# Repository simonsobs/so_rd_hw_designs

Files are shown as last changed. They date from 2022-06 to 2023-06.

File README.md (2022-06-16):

# so_rd_hw_designs
For storing design and fabrication files for circuit boards and other hardware within the readout and detector working group in a version controlled way.

## 300K LNA hardware
Ultimately, the printed circuit board (PCB) and power supply box designs should live here.

### 300K LNA PCB
The directories under`300k_amp_ps_box/pcb` contain all the files necessary for editing, fabricating, and viewing the 300K LNA circuit boards.
`300k_amp_ps_box/pcb/Bottom_board` contains a picture of the electronics schematic for the bottom board, a .step file which is a 3D model of the bottom board, and the gerber files necessary to manufacture the bottom circuit board (under `Project_Outputs_for_Bottom_Board`).
This same exact structure exists under`300k_amp_ps_box/pcb/Top_board` but instead describes the Top board of the 300K LNA PCB. In addition, [here are the assembly documents for both Top and Bottom boards](https://docs.google.com/presentation/d/1A_KDBGtZD-UfWHo1MMT_YvrvhtoMr0XffyKuqTHIMP8/edit?usp=sharing) 

#### Editing and Viewing the 300K LNA PCB with Altium
The user should copy the contents of the "altium_files" directory and place them into the directory in which their copy of Altium lives. Specifically, the user should:
  1. Copy all _directories_ under `300k_amp_ps_box/pcb/altium_files/Projects` into their Altium/Projects directory. 
  2. Place all files in `300k_amp_ps_box/pcb/altium_files/Library/ExportIntLib` into their Altium/Library/ExportIntLib directory OR just copy and place the ExportIntLib directory under User/Path/to/Altium/Library. 
  3. Open Altium and navigate to Open Project
  4. Open `300k_amp_filtered_PS_supply` to see the entire PCB project. The Top and Bottom board projects exist because the 300k_amp_filtered_PS_supply _composed of_ the two smaller projects: `Top_board` and `Bottom_board`.
  5. User should now be able to view and edit the boards. User can reference [The Altium tutorial documents](https://www.altium.com/documentation/altium-designer/tutorial-complete-design-walkthrough) for a quick guide to make edits within Altium.

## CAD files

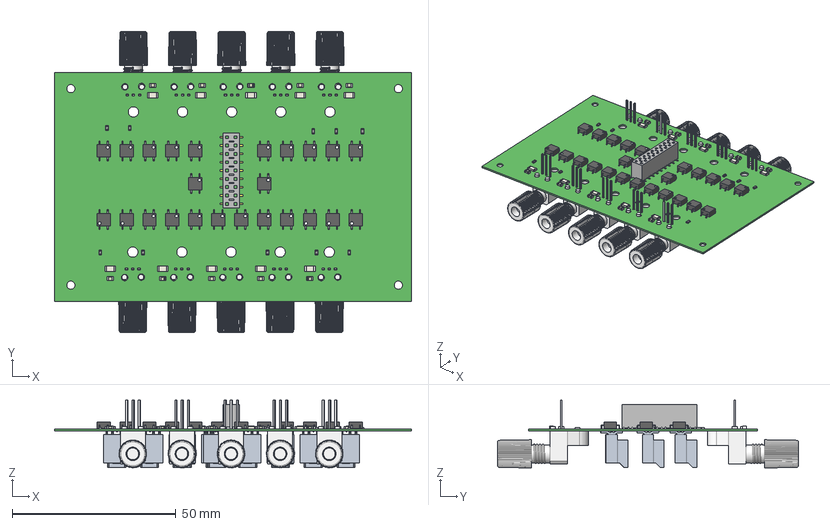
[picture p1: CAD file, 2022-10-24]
300k_amp_ps_box/pcb/Top_board/top_board_rev10_3.step
109.0 x 91.9 x 20.8 mm
C-137-019
SSM-109-STL-DV_body
Vishay_logo_-_Copy x 10
Vishay_logo x 10
Cap_KEMET_C0805C472J3HAC_eec x 30
Extruded x 54
3dmodel x 144
Detector x 10

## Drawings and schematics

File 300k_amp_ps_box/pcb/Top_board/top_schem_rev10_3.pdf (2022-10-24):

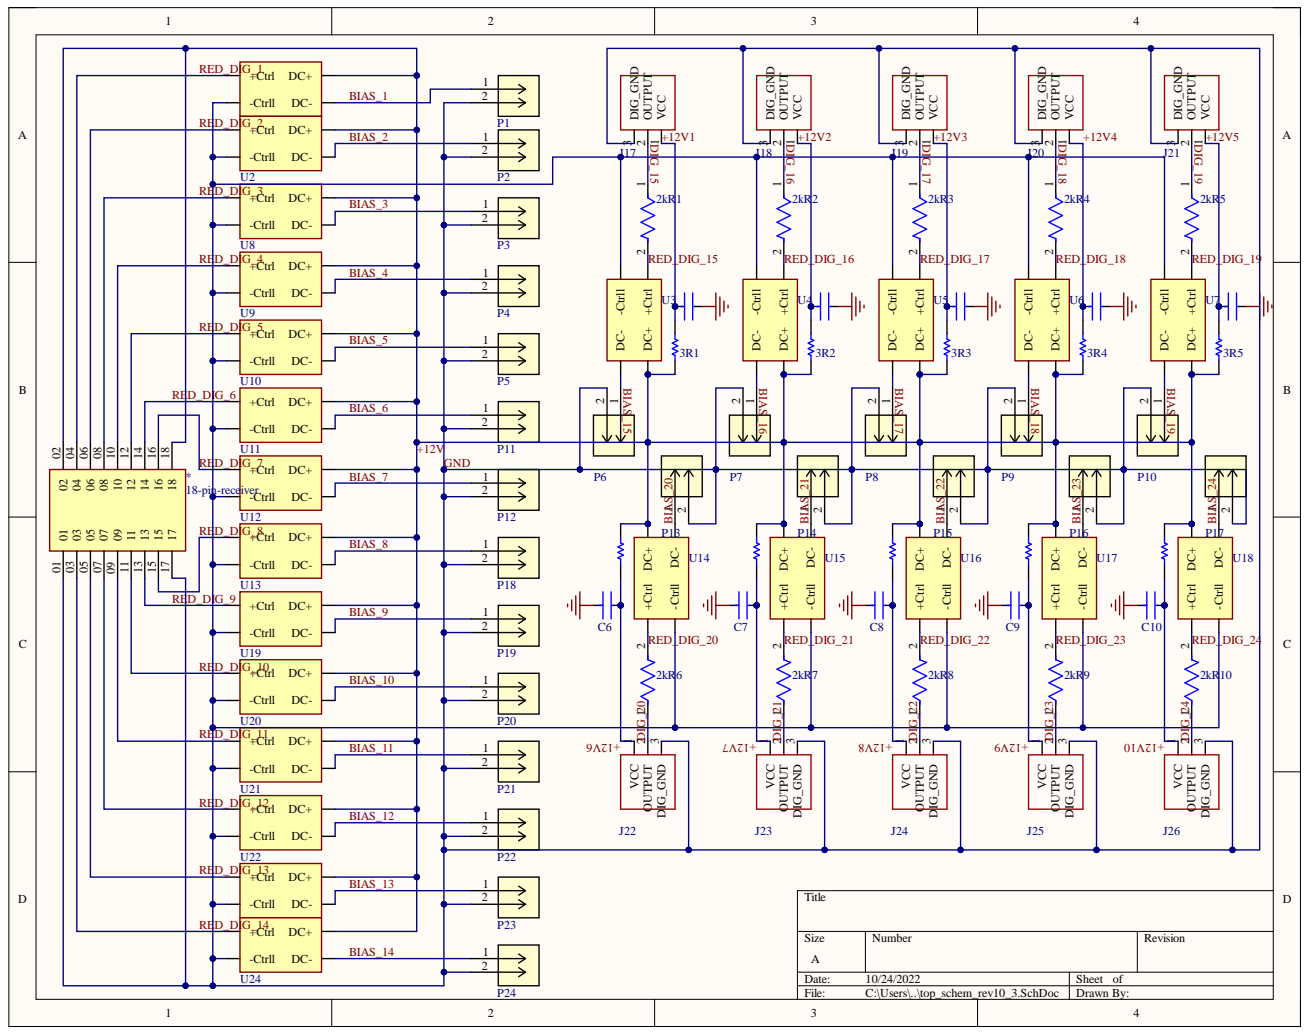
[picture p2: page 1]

BIAS_13

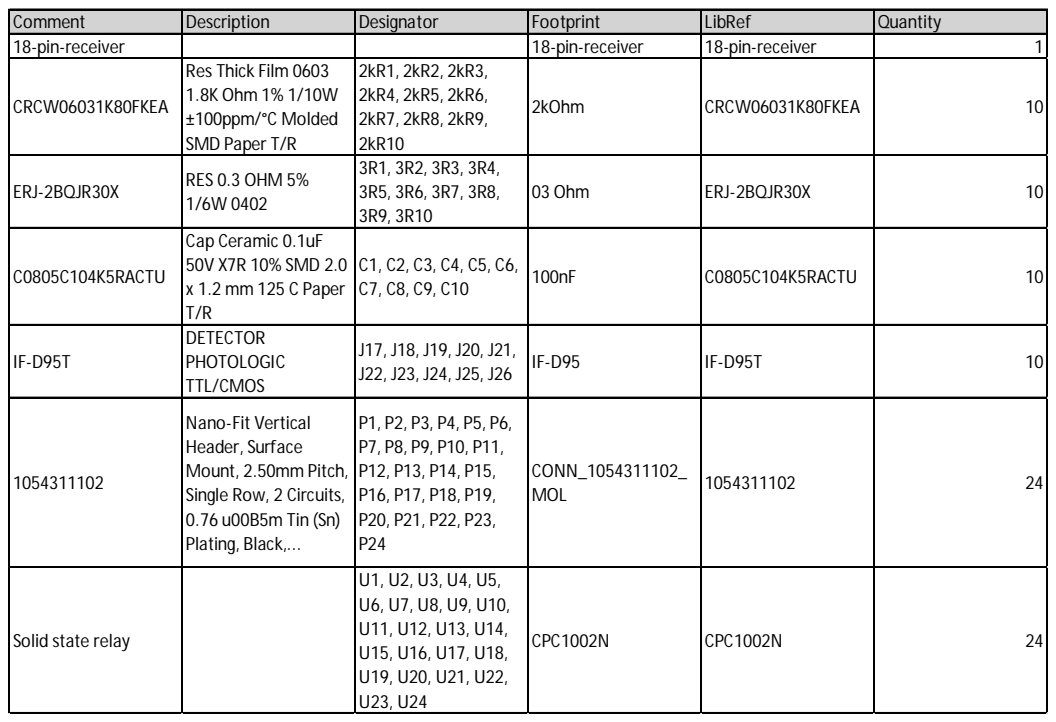
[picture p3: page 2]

Comment | Description | Designator | Footprint | LibRef | Quantity
18-pin-receiver | | | 18-pin-receiver | 18-pin-receiver | 1
CRCW06031K80FKEA | Res Thick Film 0603 1.8K Ohm 1% 1/10W ±100ppm/°C Molded SMD Paper T/R | 2kR1, 2kR2, 2kR3, 2kR4, 2kR5, 2kR6, 2kR7, 2kR8, 2kR9, 2kR10 | 2kOhm | CRCW06031K80FKEA | 10

ERJ-2BQJR30X | RES 0.3 OHM 5% 1/6W 0402 | 3R1, 3R2, 3R3, 3R4, 3R5, 3R6, 3R7, 3R8, 3R9, 3R10 | 03 Ohm | ERJ-2BQJR30X | 10

C0805C104K5RACTU | Cap Ceramic 0.1uF 50V X7R 10% SMD 2.0 x 1.2 mm 125 C Paper T/R | C1, C2, C3, C4, C5, C6, C7, C8, C9, C10 | 100nF | C0805C104K5RACTU | 10

IF-D95T | DETECTOR PHOTOLOGIC TTL/CMOS | J17, J18, J19, J20, J21, J22, J23, J24, J25, J26 | IF-D95 | IF-D95T | 10

1054311102 | Nano-Fit Vertical Header, Surface Mount, 2.50mm Pitch, Single Row, 2 Circuits, 0.76 u00B5m Tin (Sn) Plating, Black,... | P1, P2, P3, P4, P5, P6, P7, P8, P9, P10, P11, P12, P13, P14, P15, P16, P17, P18, P19, P20, P21, P22, P23, P24 | CONN_1054311102_ MOL | 1054311102 | 24

Solid state relay | | U1, U2, U3, U4, U5, U6, U7, U8, U9, U10, U11, U12, U13, U14, U15, U16, U17, U18, U19, U20, U21, U22, U23, U24 | CPC1002N | CPC1002N | 24

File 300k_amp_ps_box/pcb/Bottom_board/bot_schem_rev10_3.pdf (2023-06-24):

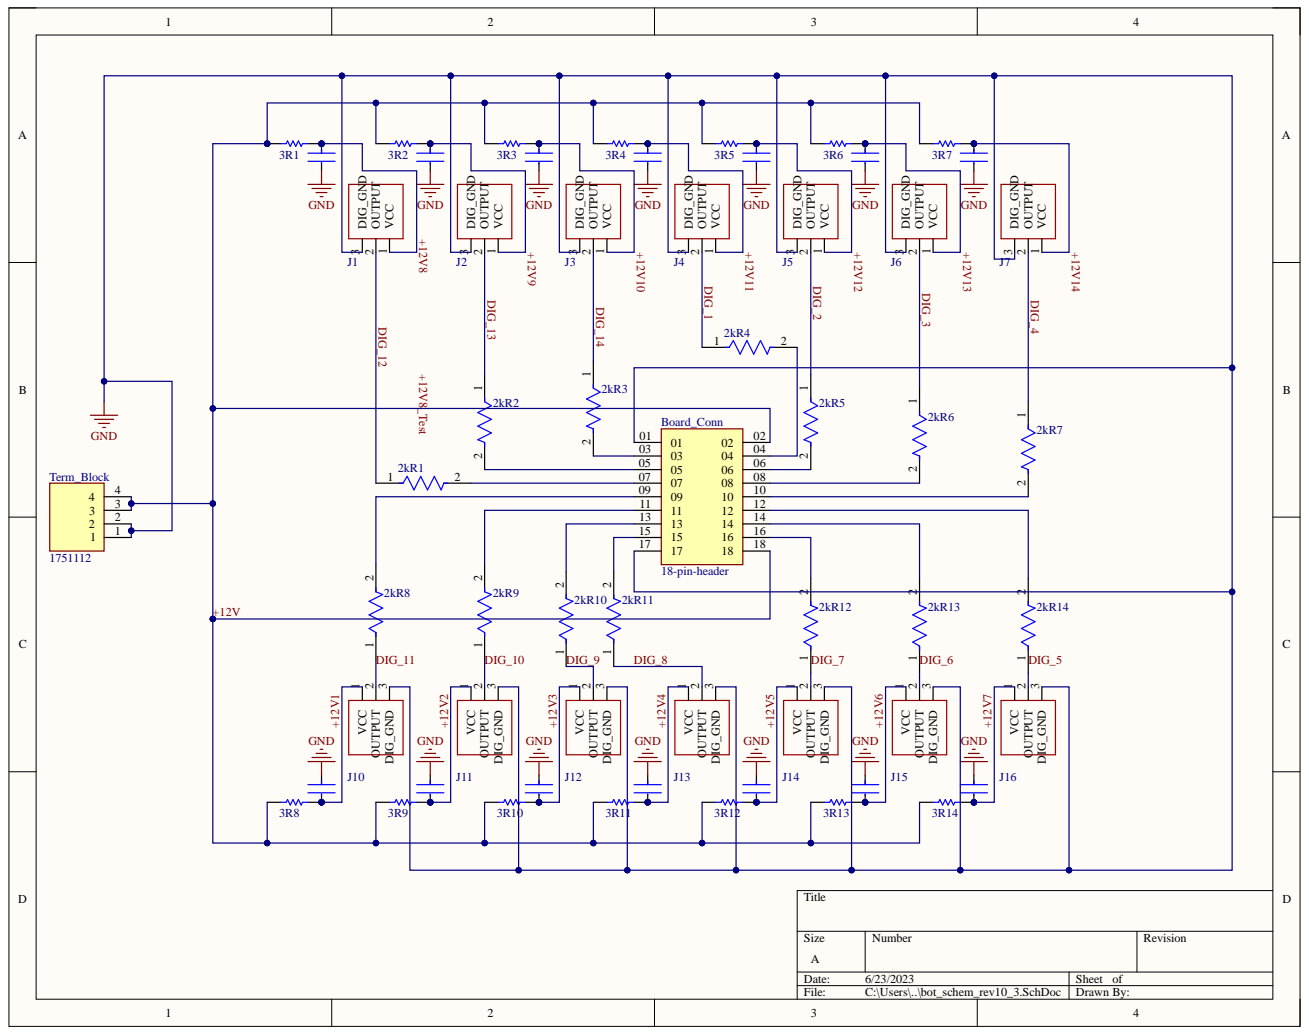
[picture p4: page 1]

11 11 12 14 16 18 | 12
13 13 | 14
15 15 | 16
17 17 | 18

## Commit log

2021-04-07 Added fabrication and 3d model files for the stacked pcb
    [bottom_board.GBL, bottom_board.GBO, bottom_board.GBP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]
2021-04-30 design updated to handle flipped optical receivers
    [bottom_board.GBL, bottom_board.GBO, bottom_board.GBP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]
2021-09-27 updated pcb design v2 - updated silkscreen layer
    [bottom_board.GBL, bottom_board.GBO, bottom_board.GBP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]
2022-05-11 reorganized file structure within pcb directory, and added pngs of schematics
    [Bottom_board.PrjPcb, Top_board.PrjPcb, basic_diagram.SchDoc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]
2022-05-25 added new revision from SeanA and TanayB from 2022.5.23
    [Bottom_board.PrjPcb, Bottom_board_rev1.PrjPcb, Top_board.PrjPcb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]
2022-06-14 Renamed part designators for both boards AS WELL AS updated bottom board design to exclude filters
    [Bottom_board_rev1.PrjPcb, Bottom_board_rev3.PrjPcb, Top_board_rev1.PrjPcb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]
2022-07-29 Thickened 2.5 Amp trace. Edited silkscreen callouts to be more clear. Bussed 2 SSRs to power plane (before up to 8 SSRs were bussed together)
    [Bottom_board_rev3.PrjPcb, Bottom_board_rev4.PrjPcb, Top_board_rev3.PrjPcb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]
2022-09-06 Added 4-pin terminal block for PS and 18-pin board connectors to design
    [Bottom_board_rev4.PrjPcb, Bottom_board_rev9.PrjPcb, Top_board_rev4.PrjPcb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]
2022-09-15 Fixed short between bias 1 and ground on top board
    [Bottom_board_rev10.PrjPcb, Bottom_board_rev9.PrjPcb, Top_board_rev10.PrjPcb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]
2022-09-16 Cleaned up silkscreen layer things. Still on Rev10
    [bottom_board_rev10.DRL, bottom_board_rev10.GBL, bottom_board_rev10.GBO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]
2022-10-18 Changed power connecting terminal to one that is in-stock
    (277-1050488-ND), or 1050488 specifically
    [Bottom_board_rev10.PrjPcb, Bottom_board_rev10_2.PrjPcb, Top_board_rev10.PrjPcb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]
2022-10-19 Changed silkscreen layer of bottom board, updated altium library
    [Bottom_board_rev10_2.PrjPcb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]
2022-10-24 Made corner holes NPTH, changed bottom_board circuit schematic, moved bottom board silkscreen layer
    Moved test receiver to the actual test receiver. Updated bottom board schematic to have designator names match silkscreen layer.
    [Bottom_board_rev10_2.PrjPcb, Bottom_board_rev10_3.PrjPcb, Top_board_rev10_2.PrjPcb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]
2023-06-23 Added bottom_board schematic
    Somehow lost the bottom board schematic in the previous iterations...
    [Bottom_board_rev10_3.PrjPcb, bot_schem_rev10_3.SchDoc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]
